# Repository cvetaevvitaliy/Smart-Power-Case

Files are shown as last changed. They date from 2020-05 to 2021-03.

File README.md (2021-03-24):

<div align="center">
 
 # Smart Power Case for FatShark, Skyzone, DJI fpv goggles
 
 
 
 
</div>

Smart Power Case for FatShark goggles <br>
Powered by a single Li-ion, stable output 8.2V or 12.6V (switching from menu)<br>
Support QC 2.0/3.0, FastCharge charges 5V, 9V, 12V - max input 18W (BQ25895) <br>
Shows operating time, remaining battery capacity, remaining charging time (BQ27441)<br>
<br>

## How to build 

###### Depends
You need install `gcc-arm-none-eabi` compiler and CMake  <br>
for Ubuntu <br>
 `sudo apt-get install gcc-arm-none-eabi cmake` <br>
for MacOS <br>
 `brew install gcc-arm-none-eabi cmake`
 
###### How to build project for STM32F103TBU
```
    git clone https://github.com/cvetaevvitaliy/Smart-Power-Case
    cd Smart-Power-Case
    mkdir build
    cd build
    cmake ..
    make -j8
```
default build for MCU STM32F103TBU (128kb flash ), if you need change type MCU - STM32F103T8U (64kb flash), please use option `-DTYPE_MCU=F103TBU` <br>
P.S. if you run `cmake ..` and want to use  `-DTYPE_MCU=F103T8U` You have two steps: <br>
First: you need delete build dir <br>
Second: remove `CMakeCache.txt` use `rm CMakeCache.txt` in build directory <br>

###### How to build project for STM32F103T8U
```$xslt
    git clone https://github.com/cvetaevvitaliy/Smart-Power-Case
    cd Smart-Power-Case
    mkdir build
    cd build
    cmake -DTYPE_MCU=F103T8U ..
    make -j8
```

Or use Clion IDE and load CMakeLists.txt file <br>

After a successful build, such files will be created<br>
:beer:   `firmware-x.x.x.bin` update for flash GUI flasher<br>
:beer:   `FullFW.bin` for flash via SWD flasher ST-link or Jlink<br>
:beers:   `FullFW.bin` has bootloader, firmware and default eeprom data<br>
<br>

#### Flash memory map for STM32F103TBU (128kb)
| 0x8000000 | 0x8000800 | 0x801FC00 | 
|:---:|:---:|:---:|
| bootloader | firmware | eeprom |
<br>

#### Flash memory map for STM32F103T8U (64kb)

| 0x8000000 | 0x8000800 | 0x800FC00 |
|:---:|:---:|:---:|
| bootloader | firmware | eeprom |

<br>
:white_check_mark: Since the data is not saved often, it made no sense to use an external eeprom

another options: `-DDEBUG=ON` for debug firmware via USB virtual comport, speed 115200, you can use `printf` and send out to console

*update project, added  support fw update from bootloader, use HID bootloader (https://github.com/cvetaevvitaliy/STM32_HID_Bootloader)<br>
*update project, added cross-platform command line flasher (https://github.com/cvetaevvitaliy/Flasher_USB_HID)<br> <br>
*update project, added cross-platform GUI flasher (https://github.com/cvetaevvitaliy/Smart-Power-Case-GUIFlasher)
Linux
MacOS
Win

YouTube link <br>https://www.youtube.com/watch?v=Y0oo7hjzqtc <br>
https://www.youtube.com/watch?v=4TmXY8NL-vo

<br><br> Download [Schematic.pdf](https://github.com/cvetaevvitaliy/Smart-Power-Case/blob/master/HW/schematic.pdf)
<br>
Download [Gerber X2.zip](https://github.com/cvetaevvitaliy/Smart-Power-Case/blob/master/HW/GerberX2_V2_2.zip)

Download STL for 3D printing <br>
MID https://github.com/cvetaevvitaliy/Smart-Power-Case/blob/master/HW/STL_File/mid.STL<br>
TOP https://github.com/cvetaevvitaliy/Smart-Power-Case/blob/master/HW/STL_File/top.STL<br>

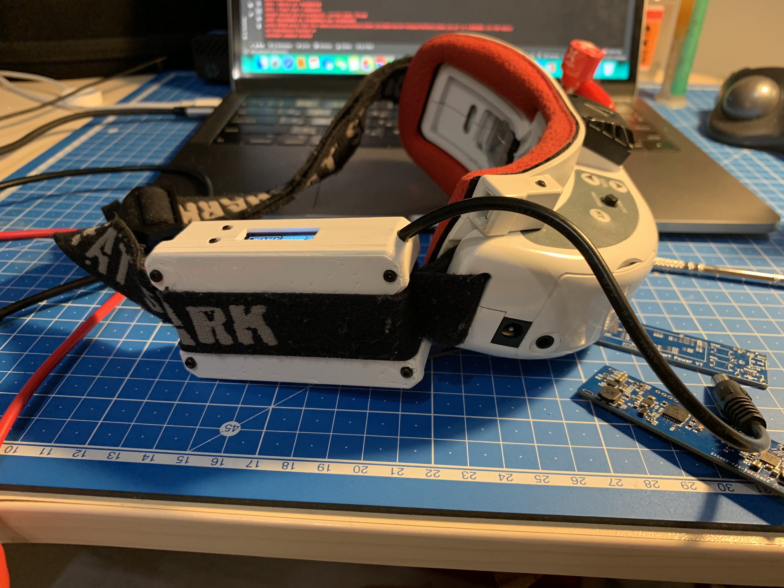
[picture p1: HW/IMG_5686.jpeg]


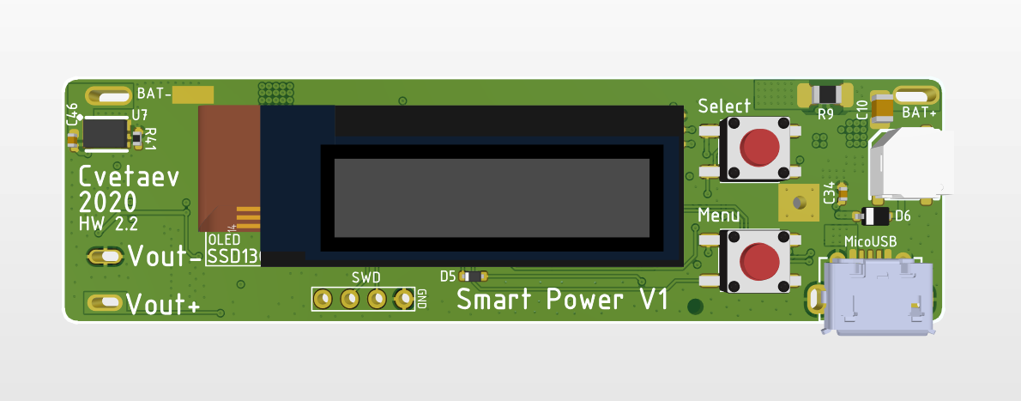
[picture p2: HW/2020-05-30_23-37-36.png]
TOP


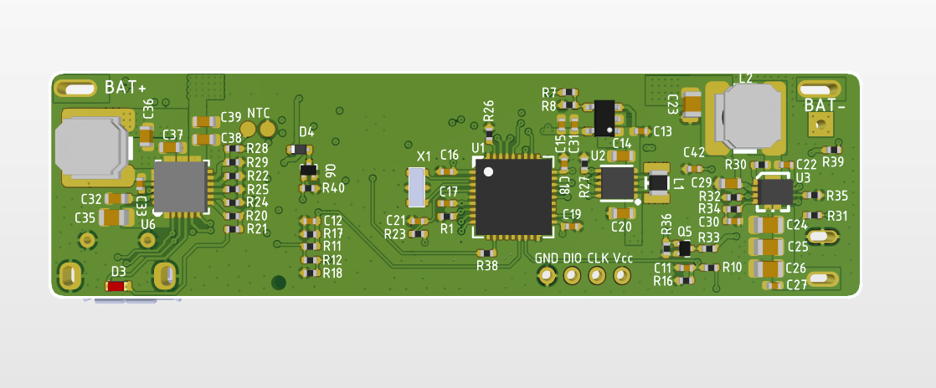
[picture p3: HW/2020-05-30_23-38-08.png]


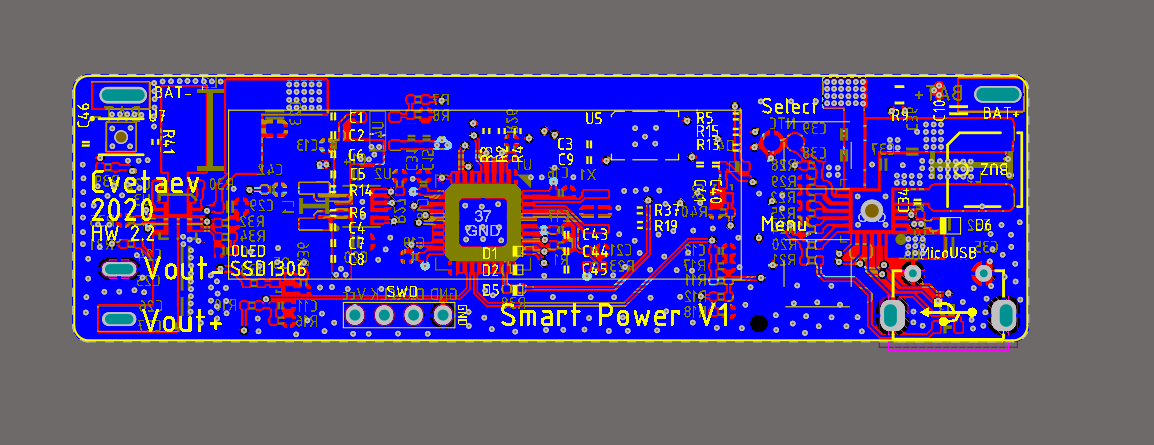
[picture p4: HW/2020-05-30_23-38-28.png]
Altium


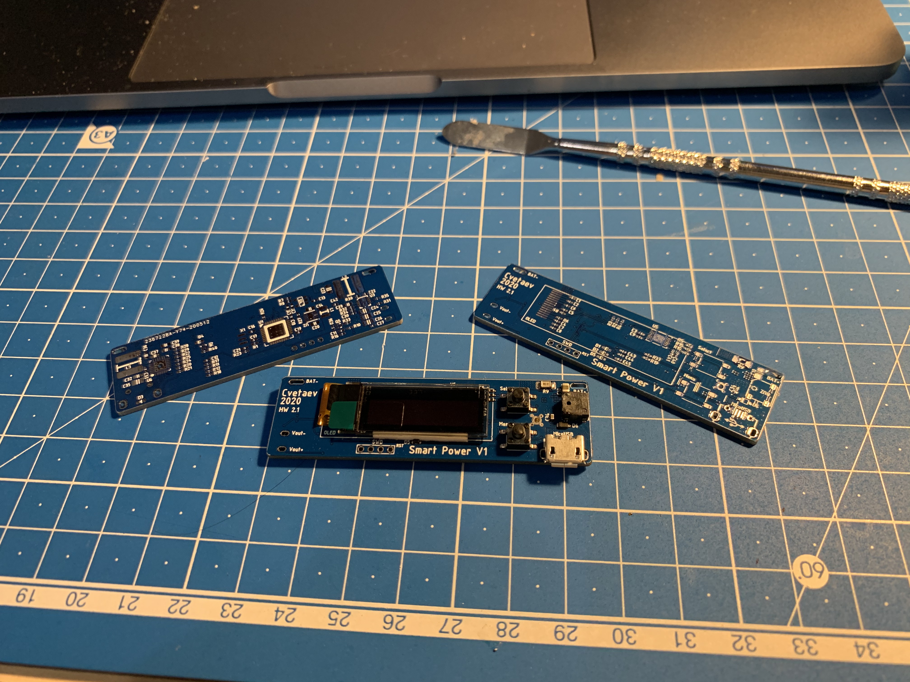
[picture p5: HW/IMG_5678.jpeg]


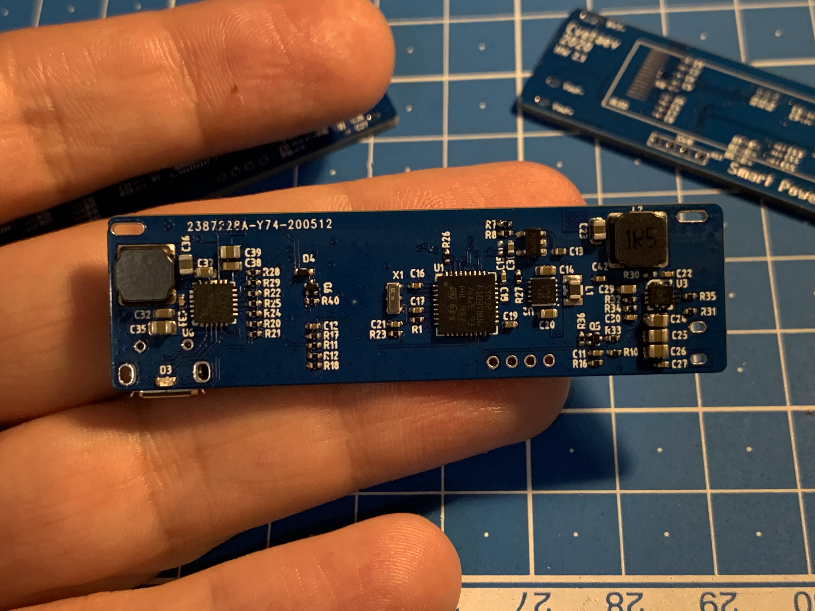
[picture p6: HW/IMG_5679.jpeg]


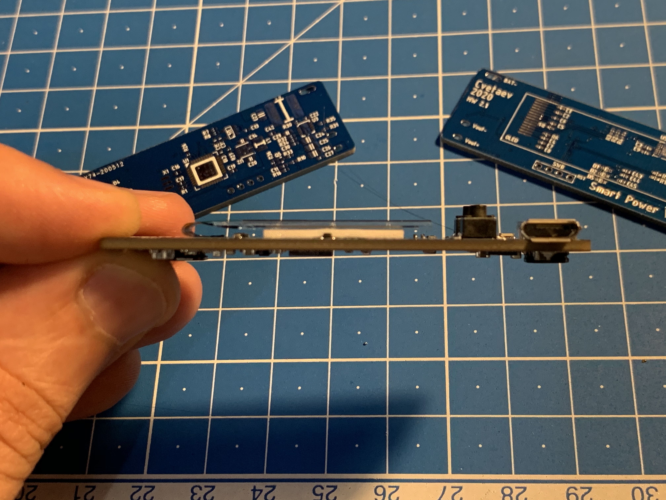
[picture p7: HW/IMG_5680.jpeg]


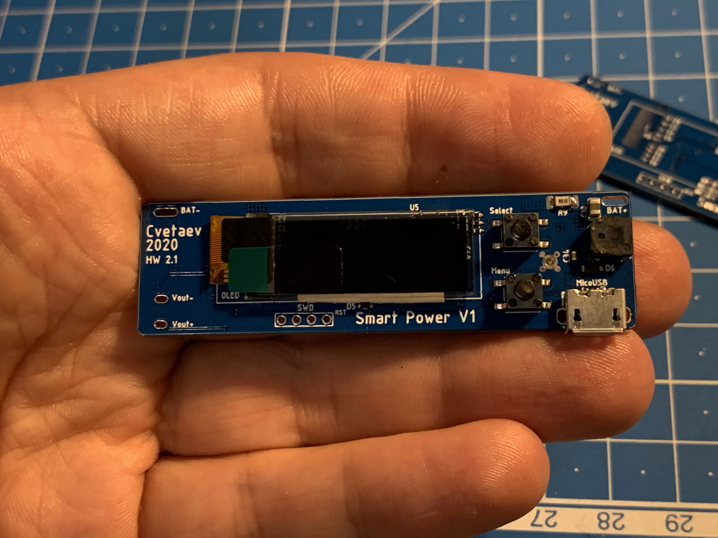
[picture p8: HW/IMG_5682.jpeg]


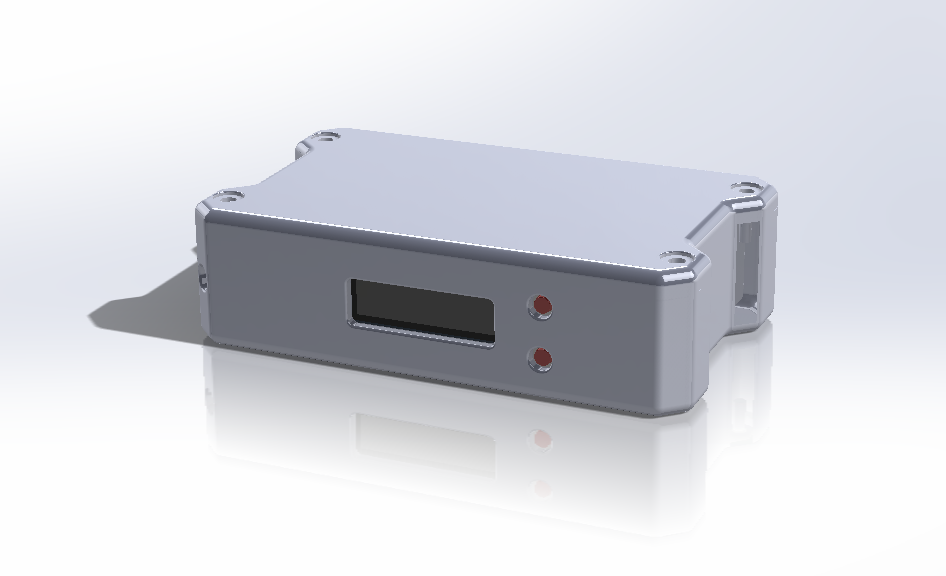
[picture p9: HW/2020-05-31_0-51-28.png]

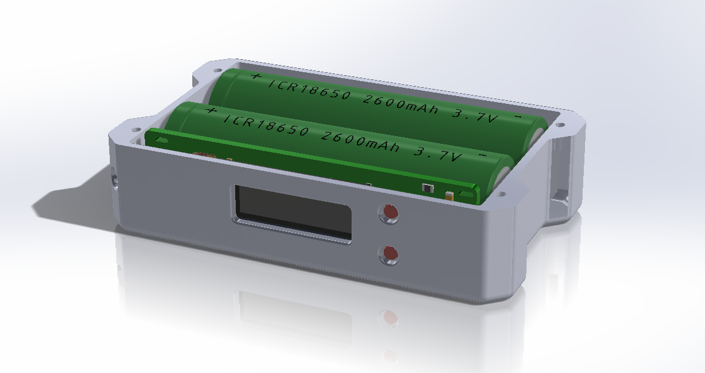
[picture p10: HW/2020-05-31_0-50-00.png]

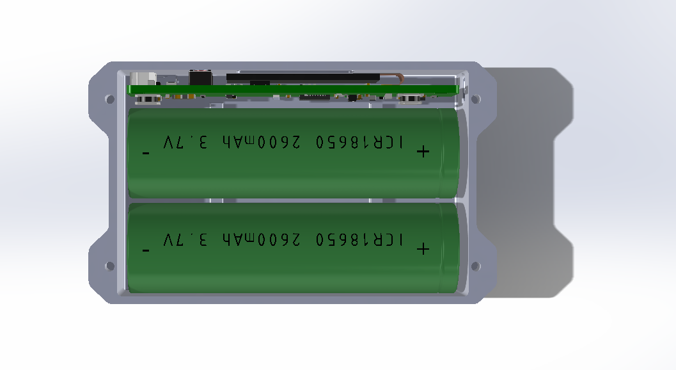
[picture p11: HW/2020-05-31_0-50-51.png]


See 3D model in the browser <br>
MID https://github.com/cvetaevvitaliy/Smart-Power-Case/blob/master/HW/STL_File/mid.STL<br>
TOP https://github.com/cvetaevvitaliy/Smart-Power-Case/blob/master/HW/STL_File/top.STL<br>

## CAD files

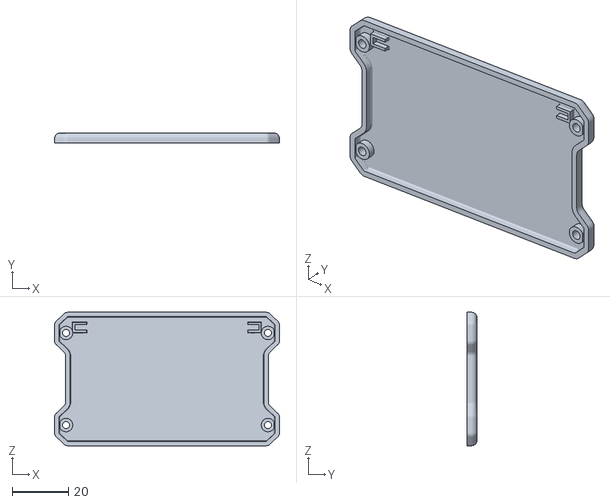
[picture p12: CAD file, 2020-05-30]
HW/STL_File/top.STL
80.0 x 3.60 x 47.5

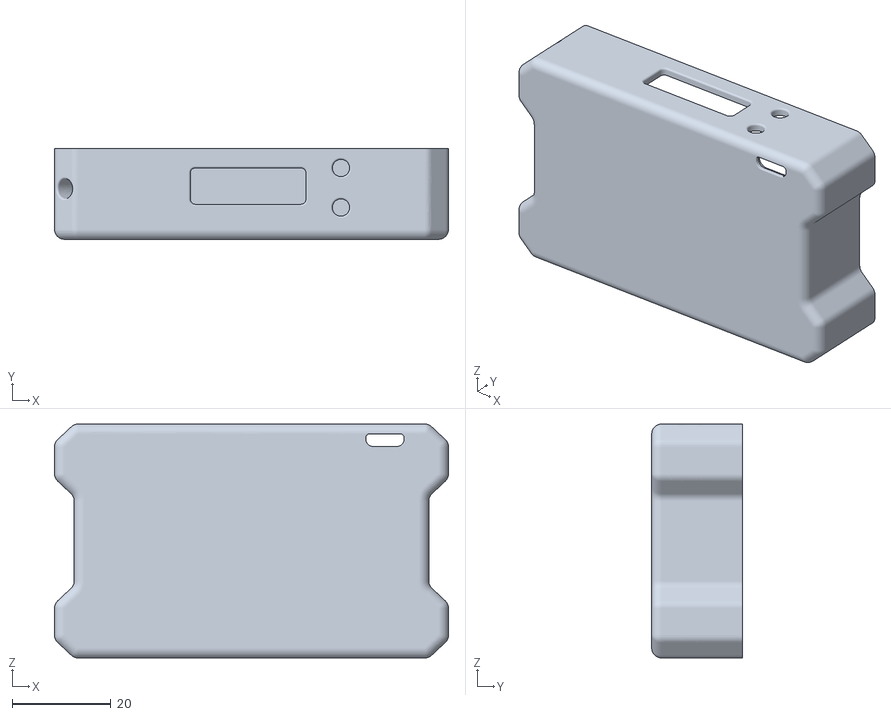
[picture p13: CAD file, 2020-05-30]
HW/STL_File/mid.STL
80.0 x 18.4 x 47.5

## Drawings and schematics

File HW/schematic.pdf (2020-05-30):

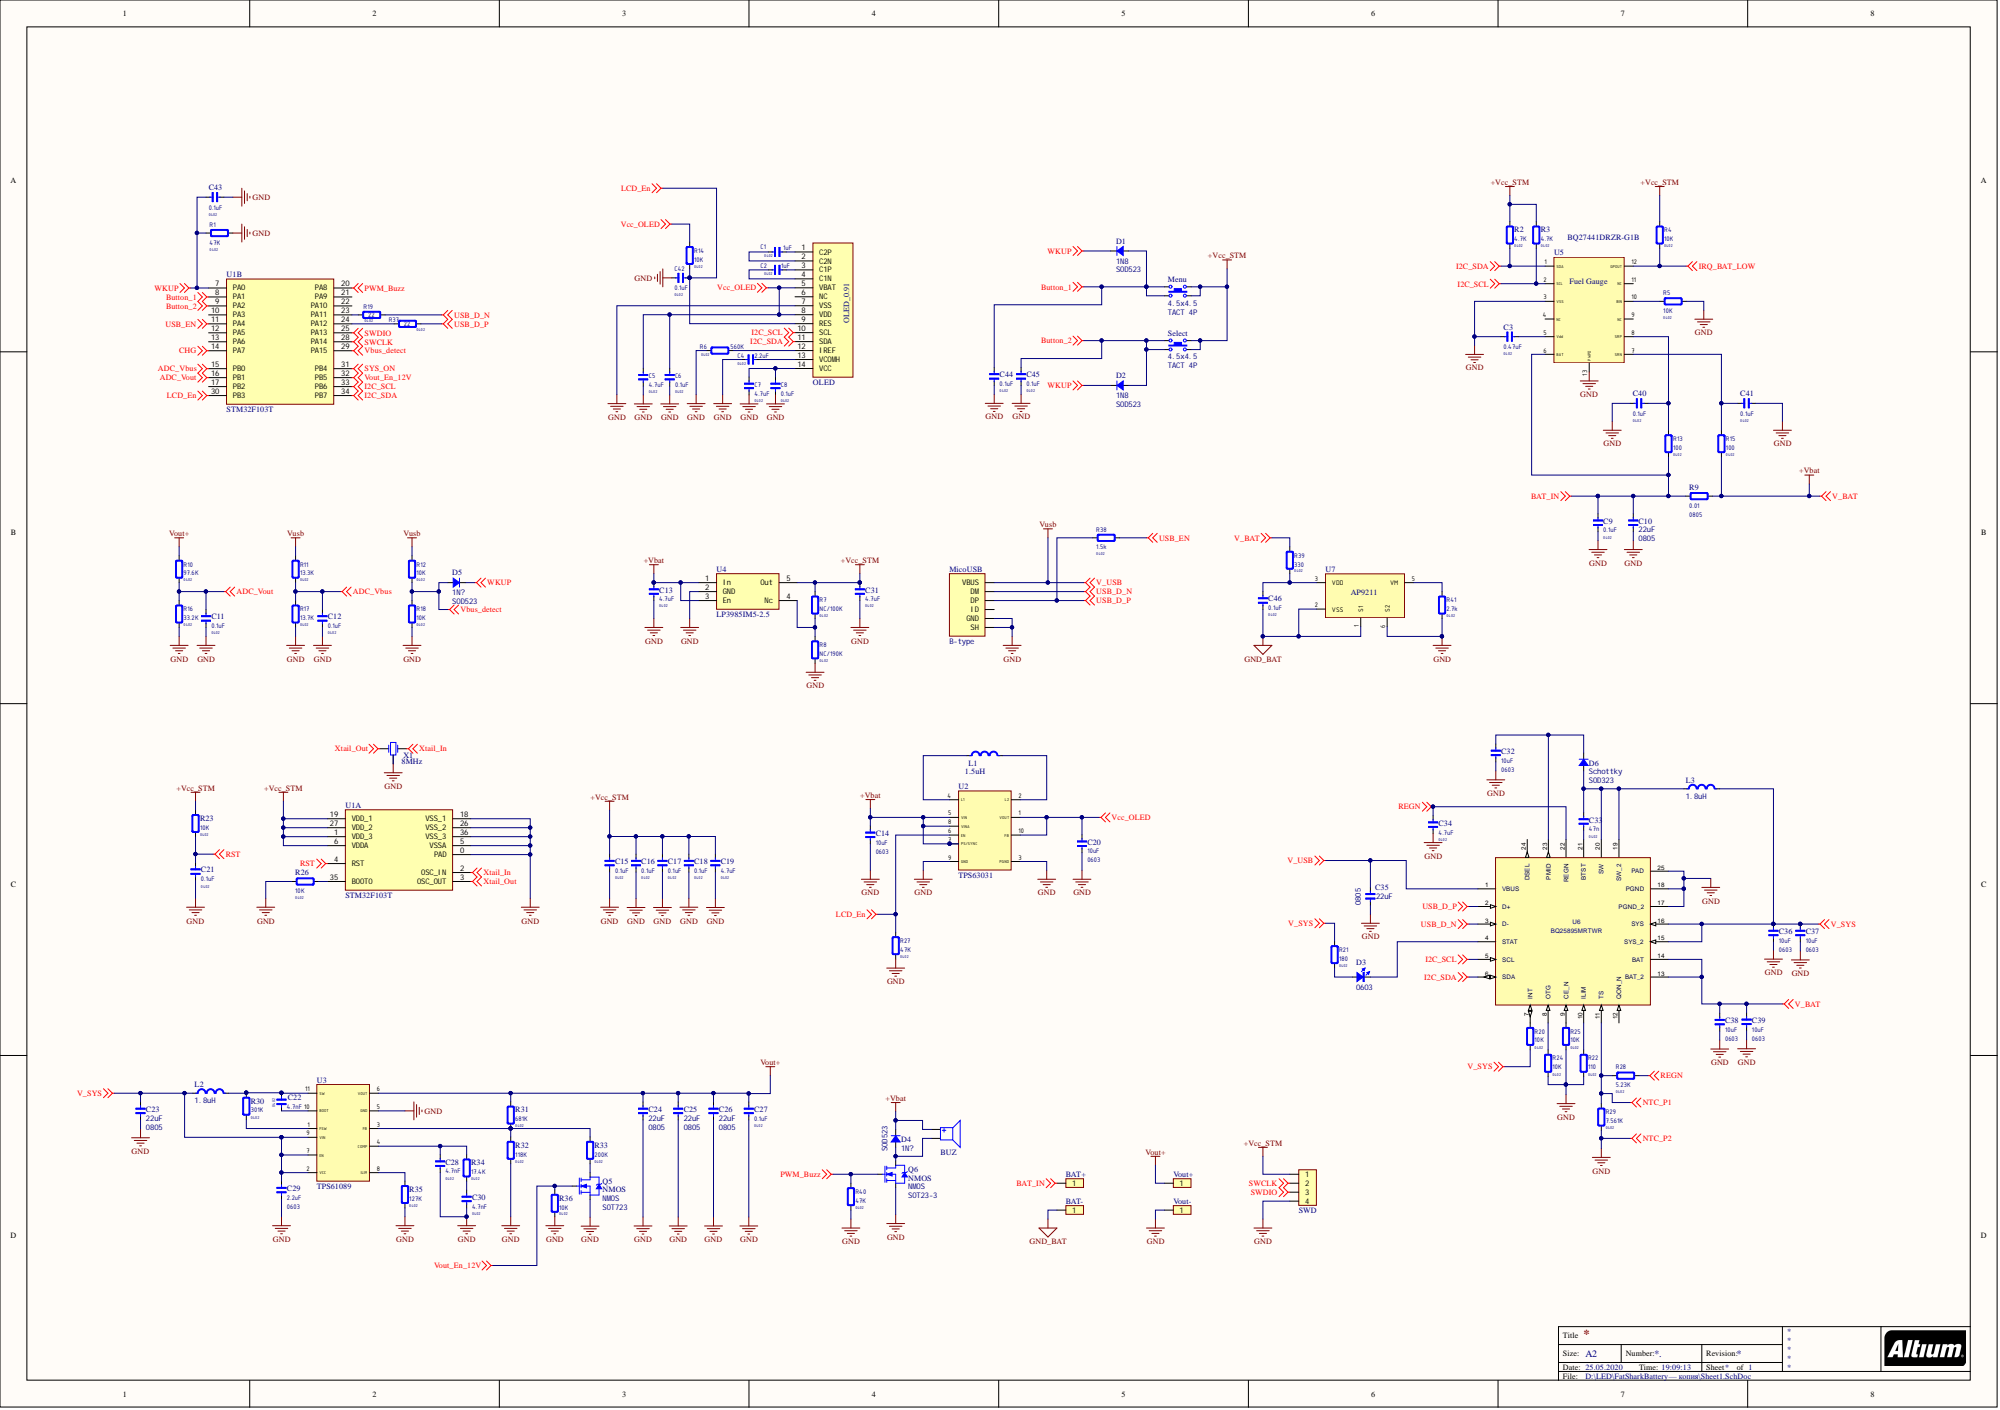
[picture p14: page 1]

PS/SYNC 7

Title * | * * * * *

Size: A2 | Number: *. | Revision: *
Date: 25.05.2020 Time: 19:09:13 | | Sheet * of 1

D:\LED\FatSharkBattery— копия\Sheet1.SchDoc

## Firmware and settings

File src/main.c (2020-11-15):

#include "main.h"
#include "stm32f1xx_hal.h"
#include "main_app.h"

ADC_HandleTypeDef hadc1;
DMA_HandleTypeDef hdma_adc1;

I2C_HandleTypeDef hi2c1;
DMA_HandleTypeDef hdma_i2c1_tx;
DMA_HandleTypeDef hdma_i2c1_rx;

RTC_HandleTypeDef hrtc;

TIM_HandleTypeDef htim1;
TIM_HandleTypeDef htim2;
TIM_HandleTypeDef htim3;

void SystemClock_Config(void);
static void MX_GPIO_Init(void);
static void MX_DMA_Init(void);
static void MX_I2C1_Init(void);
static void MX_ADC1_Init(void);
static void MX_TIM1_Init(void);
static void MX_TIM2_Init(void);
static void MX_TIM3_Init(void);
static void MX_RTC_Init(void);
static void USB_Reset_GPIO(void);
static inline void System_Init(void);

void HAL_TIM_MspPostInit(TIM_HandleTypeDef *htim);


int main(void) {

    System_Init();

    while (1) {
        App_Loop(); // main loop, what's "spinning" in the main_app module
    }

}

inline void System_Init(void){

    HAL_Init();
    SystemClock_Config();
    MX_GPIO_Init();
    MX_DMA_Init();
    MX_I2C1_Init();
    MX_ADC1_Init();
    MX_TIM1_Init();
    MX_TIM2_Init();
    MX_TIM3_Init();
    MX_RTC_Init();
    App_Setup();
    App_Init();
    if (!App_Check_StartUp())
        _Error_Handler(__FILE__, __LINE__);

}

void SystemClock_Config(void) {

    RCC_OscInitTypeDef RCC_OscInitStruct;
    RCC_ClkInitTypeDef RCC_ClkInitStruct;
    RCC_PeriphCLKInitTypeDef PeriphClkInit;

    /**Initializes the CPU, AHB and APB busses clocks 
    */
    RCC_OscInitStruct.OscillatorType = RCC_OSCILLATORTYPE_LSI | RCC_OSCILLATORTYPE_HSE;
    RCC_OscInitStruct.HSEState = RCC_HSE_ON;
    RCC_OscInitStruct.HSEPredivValue = RCC_HSE_PREDIV_DIV1;
    RCC_OscInitStruct.HSIState = RCC_HSI_ON;
    RCC_OscInitStruct.LSIState = RCC_LSI_ON;
    RCC_OscInitStruct.PLL.PLLState = RCC_PLL_ON;
    RCC_OscInitStruct.PLL.PLLSource = RCC_PLLSOURCE_HSE;
    RCC_OscInitStruct.PLL.PLLMUL = RCC_PLL_MUL6;
    if (HAL_RCC_OscConfig(&RCC_OscInitStruct) != HAL_OK) {
        _Error_Handler(__FILE__, __LINE__);
    }

    /**Initializes the CPU, AHB and APB busses clocks 
    */
    RCC_ClkInitStruct.ClockType = RCC_CLOCKTYPE_HCLK | RCC_CLOCKTYPE_SYSCLK
                                  | RCC_CLOCKTYPE_PCLK1 | RCC_CLOCKTYPE_PCLK2;
    RCC_ClkInitStruct.SYSCLKSource = RCC_SYSCLKSOURCE_PLLCLK;
    RCC_ClkInitStruct.AHBCLKDivider = RCC_SYSCLK_DIV1;
    RCC_ClkInitStruct.APB1CLKDivider = RCC_HCLK_DIV2;
    RCC_ClkInitStruct.APB2CLKDivider = RCC_HCLK_DIV2;

    if (HAL_RCC_ClockConfig(&RCC_ClkInitStruct, FLASH_LATENCY_1) != HAL_OK) {
        _Error_Handler(__FILE__, __LINE__);
    }

    PeriphClkInit.PeriphClockSelection = RCC_PERIPHCLK_RTC | RCC_PERIPHCLK_ADC
                                         | RCC_PERIPHCLK_USB;
    PeriphClkInit.RTCClockSelection = RCC_RTCCLKSOURCE_LSI;
    PeriphClkInit.AdcClockSelection = RCC_ADCPCLK2_DIV2;
    PeriphClkInit.UsbClockSelection = RCC_USBCLKSOURCE_PLL;
    if (HAL_RCCEx_PeriphCLKConfig(&PeriphClkInit) != HAL_OK) {
        _Error_Handler(__FILE__, __LINE__);
    }

    /**Configure the Systick interrupt time 
    */
    HAL_SYSTICK_Config(HAL_RCC_GetHCLKFreq() / 1000);

    /**Configure the Systick 
    */
    HAL_SYSTICK_CLKSourceConfig(SYSTICK_CLKSOURCE_HCLK);

    /* SysTick_IRQn interrupt configuration */
    HAL_NVIC_SetPriority(SysTick_IRQn, 0, 0);

    PWR->CSR |= PWR_CSR_EWUP; // Enable wakeup pin
    RCC->APB1ENR |= RCC_APB1ENR_PWREN; // enable clock for RTC BKP todo need debug
}

static void MX_ADC1_Init(void) {

    ADC_AnalogWDGConfTypeDef AnalogWDGConfig;
    ADC_ChannelConfTypeDef sConfig;

    /**Common config 
    */
    hadc1.Instance = ADC1;
    hadc1.Init.ScanConvMode = ADC_SCAN_ENABLE;
    hadc1.Init.ContinuousConvMode = ENABLE;
    hadc1.Init.DiscontinuousConvMode = DISABLE;
    hadc1.Init.ExternalTrigConv = ADC_SOFTWARE_START;
    hadc1.Init.DataAlign = ADC_DATAALIGN_RIGHT;
    hadc1.Init.NbrOfConversion = 3;
    if (HAL_ADC_Init(&hadc1) != HAL_OK) {
        _Error_Handler(__FILE__, __LINE__);
    }

    /**Configure Analog WatchDog 1 
    */
    AnalogWDGConfig.WatchdogMode = ADC_ANALOGWATCHDOG_SINGLE_REG;
    AnalogWDGConfig.HighThreshold = 0;
    AnalogWDGConfig.LowThreshold = 0;
    AnalogWDGConfig.Channel = ADC_CHANNEL_9;
    AnalogWDGConfig.ITMode = DISABLE;
    if (HAL_ADC_AnalogWDGConfig(&hadc1, &AnalogWDGConfig) != HAL_OK) {
        _Error_Handler(__FILE__, __LINE__);
    }

    /**Configure Regular Channel 
    */
    sConfig.Channel = ADC_CHANNEL_9;
    sConfig.Rank = ADC_REGULAR_RANK_1;
    sConfig.SamplingTime = ADC_SAMPLETIME_239CYCLES_5;
    if (HAL_ADC_ConfigChannel(&hadc1, &sConfig) != HAL_OK) {
        _Error_Handler(__FILE__, __LINE__);
    }

    /**Configure Regular Channel 
    */
    sConfig.Channel = ADC_CHANNEL_8;
    sConfig.Rank = ADC_REGULAR_RANK_2;
    if (HAL_ADC_ConfigChannel(&hadc1, &sConfig) != HAL_OK) {
        _Error_Handler(__FILE__, __LINE__);
    }

    /**Configure Regular Channel 
    */
    sConfig.Channel = ADC_CHANNEL_TEMPSENSOR;
    sConfig.Rank = ADC_REGULAR_RANK_3;
    if (HAL_ADC_ConfigChannel(&hadc1, &sConfig) != HAL_OK) {
        _Error_Handler(__FILE__, __LINE__);
    }

}

static void MX_I2C1_Init(void) {

    hi2c1.Instance = I2C1;
    hi2c1.Init.ClockSpeed = 100000;
    hi2c1.Init.DutyCycle = I2C_DUTYCYCLE_2;
    hi2c1.Init.OwnAddress1 = 0;
    hi2c1.Init.AddressingMode = I2C_ADDRESSINGMODE_7BIT;
    hi2c1.Init.DualAddressMode = I2C_DUALADDRESS_DISABLE;
    hi2c1.Init.OwnAddress2 = 0;
    hi2c1.Init.GeneralCallMode = I2C_GENERALCALL_DISABLE;
    hi2c1.Init.NoStretchMode = I2C_NOSTRETCH_DISABLE;
    if (HAL_I2C_Init(&hi2c1) != HAL_OK) {
        _Error_Handler(__FILE__, __LINE__);
    }

}

static void MX_RTC_Init(void) {

    /**Initialize RTC Only 
    */
    hrtc.Instance = RTC;
    hrtc.Init.AsynchPrediv = RTC_AUTO_1_SECOND;
    hrtc.Init.OutPut = RTC_OUTPUTSOURCE_ALARM;
    if (HAL_RTC_Init(&hrtc) != HAL_OK) {
        _Error_Handler(__FILE__, __LINE__);
    }

}

static void MX_TIM1_Init(void) {

    TIM_ClockConfigTypeDef sClockSourceConfig;
    TIM_MasterConfigTypeDef sMasterConfig;
    TIM_OC_InitTypeDef sConfigOC;
    TIM_BreakDeadTimeConfigTypeDef sBreakDeadTimeConfig;

    htim1.Instance = TIM1;
    htim1.Init.Prescaler = 210;
    htim1.Init.CounterMode = TIM_COUNTERMODE_UP;
    htim1.Init.Period = 140;
    htim1.Init.ClockDivision = TIM_CLOCKDIVISION_DIV1;
    htim1.Init.RepetitionCounter = 0;
    htim1.Init.AutoReloadPreload = TIM_AUTORELOAD_PRELOAD_DISABLE;
    if (HAL_TIM_Base_Init(&htim1) != HAL_OK) {
        _Error_Handler(__FILE__, __LINE__);
    }

    sClockSourceConfig.ClockSource = TIM_CLOCKSOURCE_INTERNAL;
    if (HAL_TIM_ConfigClockSource(&htim1, &sClockSourceConfig) != HAL_OK) {
        _Error_Handler(__FILE__, __LINE__);
    }

    if (HAL_TIM_PWM_Init(&htim1) != HAL_OK) {
        _Error_Handler(__FILE__, __LINE__);
    }

    sMasterConfig.MasterOutputTrigger = TIM_TRGO_RESET;
    sMasterConfig.MasterSlaveMode = TIM_MASTERSLAVEMODE_DISABLE;
    if (HAL_TIMEx_MasterConfigSynchronization(&htim1, &sMasterConfig) != HAL_OK) {
        _Error_Handler(__FILE__, __LINE__);
    }

    sConfigOC.OCMode = TIM_OCMODE_PWM1;
    sConfigOC.Pulse = 70;
    sConfigOC.OCPolarity = TIM_OCPOLARITY_HIGH;
    sConfigOC.OCNPolarity = TIM_OCNPOLARITY_HIGH;
    sConfigOC.OCFastMode = TIM_OCFAST_DISABLE;
    sConfigOC.OCIdleState = TIM_OCIDLESTATE_RESET;
    sConfigOC.OCNIdleState = TIM_OCNIDLESTATE_RESET;
    if (HAL_TIM_PWM_ConfigChannel(&htim1, &sConfigOC, TIM_CHANNEL_1) != HAL_OK) {
        _Error_Handler(__FILE__, __LINE__);
    }

    sBreakDeadTimeConfig.OffStateRunMode = TIM_OSSR_DISABLE;
    sBreakDeadTimeConfig.OffStateIDLEMode = TIM_OSSI_DISABLE;
    sBreakDeadTimeConfig.LockLevel = TIM_LOCKLEVEL_OFF;
    sBreakDeadTimeConfig.DeadTime = 0;
    sBreakDeadTimeConfig.BreakState = TIM_BREAK_DISABLE;
    sBreakDeadTimeConfig.BreakPolarity = TIM_BREAKPOLARITY_HIGH;
    sBreakDeadTimeConfig.AutomaticOutput = TIM_AUTOMATICOUTPUT_DISABLE;
    if (HAL_TIMEx_ConfigBreakDeadTime(&htim1, &sBreakDeadTimeConfig) != HAL_OK) {
        _Error_Handler(__FILE__, __LINE__);
    }

    HAL_TIM_MspPostInit(&htim1);

}

static void MX_TIM2_Init(void) {

    TIM_ClockConfigTypeDef sClockSourceConfig;
    TIM_MasterConfigTypeDef sMasterConfig;

    htim2.Instance = TIM2;
    htim2.Init.Prescaler = 580;
    htim2.Init.CounterMode = TIM_COUNTERMODE_UP;
    htim2.Init.Period = 2000;
    htim2.Init.ClockDivision = TIM_CLOCKDIVISION_DIV1;
    htim2.Init.AutoReloadPreload = TIM_AUTORELOAD_PRELOAD_DISABLE;
    if (HAL_TIM_Base_Init(&htim2) != HAL_OK) {
        _Error_Handler(__FILE__, __LINE__);
    }

    sClockSourceConfig.ClockSource = TIM_CLOCKSOURCE_INTERNAL;
    if (HAL_TIM_ConfigClockSource(&htim2, &sClockSourceConfig) != HAL_OK) {
        _Error_Handler(__FILE__, __LINE__);
    }

    sMasterConfig.MasterOutputTrigger = TIM_TRGO_RESET;
    sMasterConfig.MasterSlaveMode = TIM_MASTERSLAVEMODE_DISABLE;
    if (HAL_TIMEx_MasterConfigSynchronization(&htim2, &sMasterConfig) != HAL_OK) {
        _Error_Handler(__FILE__, __LINE__);
    }

}

/* TIM3 init function */
static void MX_TIM3_Init(void)
{

    TIM_ClockConfigTypeDef sClockSourceConfig;
    TIM_MasterConfigTypeDef sMasterConfig;

    htim3.Instance = TIM3;
    htim3.Init.Prescaler = 48000;
    htim3.Init.CounterMode = TIM_COUNTERMODE_UP;
    htim3.Init.Period = 25;
    htim3.Init.ClockDivision = TIM_CLOCKDIVISION_DIV1;
    htim3.Init.AutoReloadPreload = TIM_AUTORELOAD_PRELOAD_DISABLE;
    if (HAL_TIM_Base_Init(&htim3) != HAL_OK)
    {
        _Error_Handler(__FILE__, __LINE__);
    }

    sClockSourceConfig.ClockSource = TIM_CLOCKSOURCE_INTERNAL;
    if (HAL_TIM_ConfigClockSource(&htim3, &sClockSourceConfig) != HAL_OK)
    {
        _Error_Handler(__FILE__, __LINE__);
    }

    sMasterConfig.MasterOutputTrigger = TIM_TRGO_RESET;
    sMasterConfig.MasterSlaveMode = TIM_MASTERSLAVEMODE_DISABLE;
    if (HAL_TIMEx_MasterConfigSynchronization(&htim3, &sMasterConfig) != HAL_OK)
    {
        _Error_Handler(__FILE__, __LINE__);
    }

}

/** 
  * Enable DMA controller clock
  */
static void MX_DMA_Init(void) {
    /* DMA controller clock enable */
    __HAL_RCC_DMA1_CLK_ENABLE();

    /* DMA interrupt init */
    /* DMA1_Channel1_IRQn interrupt configuration */
    HAL_NVIC_SetPriority(DMA1_Channel1_IRQn, 0, 0);
    HAL_NVIC_EnableIRQ(DMA1_Channel1_IRQn);
    /* DMA1_Channel6_IRQn interrupt configuration */
    HAL_NVIC_SetPriority(DMA1_Channel6_IRQn, 0, 0);
    HAL_NVIC_EnableIRQ(DMA1_Channel6_IRQn);
    /* DMA1_Channel7_IRQn interrupt configuration */
    HAL_NVIC_SetPriority(DMA1_Channel7_IRQn, 0, 0);
    HAL_NVIC_EnableIRQ(DMA1_Channel7_IRQn);
}

/** Configure pins as 
        * Analog 
        * Input 
        * Output
        * EVENT_OUT
        * EXTI
*/
static void MX_GPIO_Init(void) {

    GPIO_InitTypeDef GPIO_InitStruct;

    /* GPIO Ports Clock Enable */
    __HAL_RCC_GPIOD_CLK_ENABLE();
    __HAL_RCC_GPIOA_CLK_ENABLE();
    __HAL_RCC_GPIOB_CLK_ENABLE();

    /*Configure GPIO pin Output Level */
    HAL_GPIO_WritePin(GPIOA, USB_En_Pin | Bust_En_Pin, GPIO_PIN_RESET);

    /*Configure GPIO pin Output Level */
    HAL_GPIO_WritePin(GPIOB, LCD_En_Pin | SYS_On_Pin | Vout_En_12V_Pin, GPIO_PIN_RESET);

    /*Configure GPIO pins : Button_Menu_Pin Button_Select_Pin CHG_Pin Vbus_detect_Pin */
    GPIO_InitStruct.Pin = Button_Menu_Pin | Button_Select_Pin | CHG_Pin | Vbus_detect_Pin;
    GPIO_InitStruct.Mode = GPIO_MODE_IT_RISING;
    GPIO_InitStruct.Pull = GPIO_PULLDOWN;
    HAL_GPIO_Init(GPIOA, &GPIO_InitStruct);

    /*Configure GPIO pins : USB_En_Pin Bust_En_Pin */
    GPIO_InitStruct.Pin = USB_En_Pin | Bust_En_Pin;
    GPIO_InitStruct.Mode = GPIO_MODE_OUTPUT_PP;
    GPIO_InitStruct.Pull = GPIO_NOPULL;
    GPIO_InitStruct.Speed = GPIO_SPEED_FREQ_LOW;
    HAL_GPIO_Init(GPIOA, &GPIO_InitStruct);

    /*Configure GPIO pins : LCD_En_Pin SYS_On_Pin Vout_En_12V_Pin */
    GPIO_InitStruct.Pin = LCD_En_Pin | SYS_On_Pin | Vout_En_12V_Pin;
    GPIO_InitStruct.Mode = GPIO_MODE_OUTPUT_PP;
    GPIO_InitStruct.Pull = GPIO_NOPULL;
    GPIO_InitStruct.Speed = GPIO_SPEED_FREQ_LOW;
    HAL_GPIO_Init(GPIOB, &GPIO_InitStruct);

    /* EXTI interrupt init*/
    HAL_NVIC_SetPriority(EXTI1_IRQn, 0, 0);
    HAL_NVIC_EnableIRQ(EXTI1_IRQn);

    HAL_NVIC_SetPriority(EXTI2_IRQn, 0, 0);
    HAL_NVIC_EnableIRQ(EXTI2_IRQn);

    HAL_NVIC_SetPriority(EXTI9_5_IRQn, 0, 0);
    HAL_NVIC_EnableIRQ(EXTI9_5_IRQn);

    HAL_NVIC_SetPriority(EXTI15_10_IRQn, 0, 0);
    HAL_NVIC_EnableIRQ(EXTI15_10_IRQn);

}

void USB_Reset_GPIO(void) {
    GPIO_InitTypeDef GPIO_InitStruct;

    GPIO_InitStruct.Pin = GPIO_PIN_12;
    GPIO_InitStruct.Mode = GPIO_MODE_OUTPUT_PP;
    GPIO_InitStruct.Pull = GPIO_NOPULL;
    GPIO_InitStruct.Speed = GPIO_SPEED_FREQ_LOW;
    HAL_GPIO_Init(GPIOA, &GPIO_InitStruct);

    HAL_GPIO_WritePin(GPIOA, GPIO_PIN_12, GPIO_PIN_RESET);

    HAL_Delay(100);
    HAL_GPIO_DeInit(GPIOA, GPIO_PIN_12);

}

/**
  * @brief  This function is executed in case of error occurrence.
  * @param  file: The file name as string.
  * @param  line: The line in file as a number.
  * @retval None
  */
void _Error_Handler(char *file, int line) {
    /* User can add his own implementation to report the HAL error return state */
    HAL_RTCEx_BKUPWrite(&hrtc, 4, 0x424C);
    HAL_Delay(1000);
    while (1) {
        NVIC_SystemReset();
    }
}

#ifdef  USE_FULL_ASSERT
/**
  * @brief  Reports the name of the source file and the source line number
  *         where the assert_param error has occurred.
  * @param  file: pointer to the source file name
  * @param  line: assert_param error line source number
  * @retval None
  */
void assert_failed(uint8_t* file, uint32_t line)
{
  /* User can add his own implementation to report the file name and line number,
     tex: printf("Wrong parameters value: file %s on line %d\r\n", file, line) */
}
#endif /* USE_FULL_ASSERT */

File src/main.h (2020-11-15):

#ifndef __MAIN_H__
#define __MAIN_H__
#include "tinyprintf.h"
#define Error_Handler() _Error_Handler(__FILE__, __LINE__)

#define Button_Menu_Pin GPIO_PIN_1
#define ButtonMenu_GPIO_Port GPIOA
#define ButtonMenu_EXTI_IRQn EXTI1_IRQn
#define Button_Select_Pin GPIO_PIN_2
#define ButtonSelect_GPIO_Port GPIOA
#define ButtonSelect_EXTI_IRQn EXTI2_IRQn
#define USB_En_Pin GPIO_PIN_4
#define USB_En_GPIO_Port GPIOA
#define Bust_En_Pin GPIO_PIN_5
#define Bust_En_GPIO_Port GPIOA
#define CHG_Pin GPIO_PIN_7
#define CHG_GPIO_Port GPIOA
#define CHG_EXTI_IRQn EXTI9_5_IRQn
#define PWM_Buzz_Pin GPIO_PIN_8
#define PWM_Buzz_GPIO_Port GPIOA
#define Vbus_detect_Pin GPIO_PIN_15
#define Vbus_detect_GPIO_Port GPIOA
#define Vbus_detect_EXTI_IRQn EXTI15_10_IRQn
#define LCD_En_Pin GPIO_PIN_3
#define LCD_En_GPIO_Port GPIOB
#define SYS_On_Pin GPIO_PIN_4
#define SYS_On_GPIO_Port GPIOB
#define Vout_En_12V_Pin GPIO_PIN_5
#define Vout_En_12V_GPIO_Port GPIOB


void _Error_Handler(char *, int);

#endif

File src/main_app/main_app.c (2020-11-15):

/********************************
* Created by Vitaliy on 4/28/20.
********************************/
#include "main_app.h"
#include "adc.h"
#include "OLED_UI.h"
#include "button.h"
#include "Power.h"
#include "Settings_Eeprom.h"
#include "Debug.h"
#include "cli.h"

#define MAGIC_BKP_VALUE_BOOT                   ((uint32_t)0x424C) /// this value for write to BKP RTC register, to enable bootloader after reboot
#define MAGIC_BKP_VALUE_BQ                     ((uint32_t)0x425C)

extern DMA_HandleTypeDef hdma_adc1;
extern I2C_HandleTypeDef hi2c1;
extern RTC_HandleTypeDef hrtc;
extern TIM_HandleTypeDef htim2;

static Device_Status_t Device_Status = {0};

static void Time_Task(Device_Status_t *Data);
static void Enter_DFU_Mode(Device_Status_t *Data);

void App_Setup(void){

    HAL_TIM_Base_Start_IT(&htim2);
    //Settings_SetDefault(&Device_Status.Device_Settings);
    Settings_Get(&Device_Status.Device_Settings);
    if (Device_Status.Device_Settings.low_volt < 250 || Device_Status.Device_Settings.low_volt > 400) {
        Settings_SetDefault(&Device_Status.Device_Settings);
    }
}

void App_Init(void){

    CLI_Init(CLI_TDC_None);
    CLI_cmd_init();

    if (Power_ChargerInit() == false){
        Device_Status.Device_Error = Device_Error_BQ25895;
        Device_Status.system_critical_error = true;
#if 0
        LOG_DEBUG("ADC BQ25895\n");
#endif
    }

    if (ADC_Init() == false){
        Device_Status.Device_Error = Device_Error_ADC;
        Device_Status.system_critical_error = true;
#if 0
        LOG_DEBUG("ADC Error\n");
#endif
    }
    if (BQ27441_init() == false) {
        Device_Status.Device_Error = Device_Error_BQ27441;
        Device_Status.system_critical_error = true;
#if 0
        LOG_DEBUG("BQ27441 not found\n");
#endif
    }

    Power_OLEDOn(true);
    Power_BoostEnable(true);
    if (ssd1306_Init() == false) {
        Device_Status.Device_Error = Device_Error_SSD1306;
        Device_Status.system_critical_error = true;
#if 0
        LOG_DEBUG("ssd1306 not found\n");
#endif
        Power_OLEDOn(false);
        Power_SystemOn(false);
        Power_BoostEnable(false);
    } else {
        ssd1306_Draw_String("System Init", 20, 10, &Font_8x10);
        ssd1306_Draw_String(SOFTWARE_VERSION, 40, 20,&Font_8x10);
        ssd1306_UpdateScreen();
        HAL_Delay(1500);
        ssd1306_Clear();
    }

}

bool App_Check_StartUp(void){

    if (Device_Status.system_critical_error == true){
#if 0
        LOG_DEBUG("Error %d\n", Device_Status.Device_Error);
#endif
        if (Device_Status.Device_Error != Device_Error_SSD1306) {
            ssd1306_Draw_String("Error System", 0, 0, &Font_8x10);
            ssd1306_Draw_String(print_error[Device_Status.Device_Error], 0, 10, &Font_8x10);
            ssd1306_UpdateScreen();
            HAL_Delay(2000);
            ssd1306_Clear();
        }
        return false;
    } else {
        Power_SystemOn(true);
        Power_BoostEnable(true);
        if (Device_Status.Device_Settings.Boost_mode == Boost_12V)
            Power_BoostEnable12V(true);
        else
            Power_BoostEnable12V(false);
    }

    if (HAL_RTCEx_BKUPRead(&hrtc, 8) != MAGIC_BKP_VALUE_BQ){
        HAL_RTCEx_BKUPWrite(&hrtc, 8, MAGIC_BKP_VALUE_BQ);
        ssd1306_Draw_String("Reset BQ27441", 0, 0, &Font_8x10);
        ssd1306_UpdateScreen();
        BQ27441_Full_Reset();
        HAL_Delay(5000);
    }


    if (BQ27441_itporFlag() ) {
        ssd1306_Draw_String("Find NEW BAT", 0, 0, &Font_8x10);
        ssd1306_Draw_String("Please", 0, 10, &Font_8x10);
        ssd1306_Draw_String("Recalibrate", 0, 20, &Font_8x10);
        ssd1306_UpdateScreen();
        Device_Status.need_calibrate = true;
        HAL_Delay(2000);
    } else {
        Device_Status.need_calibrate = false;
        //BQ27441_CLEAR_HIBERNATE();
        //Settings_SetMinLiionVoltPowerOff((Device_Status.Device_Settings.low_volt * 10));
    }
    return true;

}


void App_Loop(void){

    Time_Task(&Device_Status);
    //ADC_Task(&Device_Status.ADC_Data);
    Button_Task(&Device_Status.Device_Settings);
    OLED_UI_Task(&Device_Status);
    Power_BatteryTask(&Device_Status);
    Power_ChargerTask(&Device_Status.ChargeChip);
#if 0
    Debug_Task(&Device_Status);
#endif

    Enter_DFU_Mode(&Device_Status);
    if (Get_Enable_USB())
        CLI_Service();


    if (!Device_Status.Device_Settings.locked_power_off && Device_Status.ChargeChip.charging_status == 0){
        if (Button_GetState(Button_select)){
            Power_DCDC();
            Device_Status.time_for_auto_off = 0;
        }

    }

}

static void Time_Task(Device_Status_t *Data){

    static uint32_t last_time = 0;
    if (HAL_GetTick() - last_time > 1000){
        last_time = HAL_GetTick();
        Data->work_time_second++;
        if (Data->work_time_second == 60){
            Data->work_time_minute++;
            if (Data->ChargeChip.Vbus < 3500)
                Data->time_for_auto_off++;
            Data->work_time_second = 0;
            if (Data->work_time_minute == 60) {
                Data->work_time_minute = 0;
                Data->work_time_hours++;
                if (Data->work_time_hours == 10) {
                    Data->work_time_hours = 0;
                }
            }
        }
    }
    Power_DevicePowerOffTimer(Data);
}

static void Enter_DFU_Mode(Device_Status_t *Data) {

    if (HAL_GPIO_ReadPin(ButtonMenu_GPIO_Port, Button_Menu_Pin) &&
        HAL_GPIO_ReadPin(ButtonSelect_GPIO_Port, Button_Select_Pin)) {
        if (Data->ChargeChip.vbus_type == BQ2589X_VBUS_USB_SDP || Data->ChargeChip.vbus_type == BQ2589X_VBUS_USB_CDP) {
            Data->ADC_Data.Vbus = 0;
            Activate_DFU();
        } else {
            ssd1306_Clear();
            ssd1306_Draw_String("Reboot", 30, 10, &Font_8x10);
            ssd1306_UpdateScreen();
            HAL_Delay(1000);
            NVIC_SystemReset(); // Uncomment this, if need reset for debug FW
        }

    }
}


Device_Status_t* Get_Device_Status(void){

    return &Device_Status;
}

void Activate_DFU(void){
    ssd1306_Clear();
    ssd1306_Draw_String("DFU 3.0", 30, 10, &Font_8x10);
    ssd1306_UpdateScreen();
    HAL_RTCEx_BKUPWrite(&hrtc, 4, MAGIC_BKP_VALUE_BOOT);
    HAL_Delay(1000);
    NVIC_SystemReset();

}

bool Settings_Get_Buzzer(void){

    Settings_Get(&Device_Status.Device_Settings);
    return Device_Status.Device_Settings.buzzer_enable;
}

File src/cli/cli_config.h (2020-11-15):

/*************************************************************************
 *
 *			CLI configure file
 *
 *	---------------------------------------------------------------------
 *
 *
 ************************************************************************/

#ifndef _CLI_CONFIG_H_
#define _CLI_CONFIG_H_

#include <stdbool.h>
#include <stdint.h>
#include <stdlib.h>
#include <string.h>
#include "cli.h"
#include "tinyprintf.h"


// ****************************** Code keys ********************************

#define _KEY_INIT(c)                       ((char)c)

#define TERM_KEY_ENTER                      (_KEY_INIT(0x0D))        // Enter command symbol
#define TERM_KEY_BACKSPACE                  (_KEY_INIT(0x08))        // Delete character before cursor position
#define TERM_KEY_LSHIFT                     (_KEY_INIT(0x08))        // Left shift symbol
#define TERM_KEY_ESCAPE                     (_KEY_INIT(0xF0))        // Exception execute command symbol
#define TERM_KEY_UP                         (_KEY_INIT(0xF1))        // KeyUp symbol
#define TERM_KEY_RIGHT                      (_KEY_INIT(0xF2))        // KeyRight symbol
#define TERM_KEY_DOWN                       (_KEY_INIT(0xF3))        // KeyDown symbol
#define TERM_KEY_LEFT                       (_KEY_INIT(0xF4))        // KeyLeft symbol
#define TERM_KEY_DEL                        (_KEY_INIT(0xF5))        // Delete character after cursor position
#define TERM_KEY_HOME                       (_KEY_INIT(0xA0))        // Home key
#define TERM_KEY_END                        (_KEY_INIT(0xA1))        // End key
#define TERM_KEY_TAB                        (_KEY_INIT(0x09))        // TAB key
#define TERM_KEY_CONF                       (_KEY_INIT(0x60))        // Configurator

// **************************************************************************

// **********************    CLI Settings   *********************************

#ifndef GIT_BRANCH
#define GIT_BRANCH               ("__________")   //If no version has been specified -DGIT_BRANCH will be empty
#endif
#ifndef GIT_HASH
#define GIT_HASH                 ("________")     //If no version has been specified -GIT_HASH will be empty
#endif
#ifndef MINOR
#define MINOR                    ("_")            //If no version has been specified -GMINOR will be empty
#endif
#ifndef MAJOR
#define MAJOR                    ("_")            //If no version has been specified -GMAJOR will be empty
#endif
#ifndef PATCH
#define PATCH                    ("_")            //If no version has been specified -GPATCH will be empty
#endif
#ifndef MCU
#define MCU                    ("_________")      //If no version has been specified -GMCU will be empty
#endif

#define _TERM_VER_                      ("v0.0.2")          // Terminal version
#define CLI_SIZE_TASK                   (20)                // Max number of commands
#define CLI_CMD_BUF_SIZE                (40)                // Max number of character buffer string command
#define CLI_CMD_LOG_SIZE                (10)                // Max number of loging command
#define CLI_ARGS_BUF_SIZE               (10)                // Max number of arguments in one command
#define CLI_ARG_SIZE                    (5)                 // Max number character of one arguments
#define CHAR_INTERRUPT                  (0x03)              // Abort execute command key-code symbol
#define STRING_TERM_ENTER               ("\n\r")            // String new line
#define STRING_TERM_ARROW               (">> ")             // String arrow enter

#define CLI_TIMELEFT_EN                     (1)            // Calculate time (If you need performance, don't turn it on )
#define CLI_CMD_LOG_EN                      (1)            // Command logging (history)
#define CLI_CMD_AUTOCMPLT_EN                (1)            // Command AutoComplete
#define CLI_LR_KEY_EN                       (1)            // Move cursor left-rigth
#define CLI_DEFAULT_ALLOC_EN                (0)            // Default Memory Allocate functions (use static or malloc memmory for add new command)
#define CLI_DEFAULT_STRING_EN               (1)            // Default String functions
#define CLI_PRINT_ERROR_EXEC_EN             (1)            // Print error after execute command
#define CLI_PRINT_ERROR_ADD_CMD_EN          (1)            // Print error after added command
#define ECHO_EN                             (1)            // Enter echo enable

// **************************************************************************

// *************************   IO CLI Settings    ***************************
void CLI_PrintStr(char* str);
void CLI_PrintChar(char c);

extern char dbgbuffer[128];
#define CLI_Printf(...)         {sprintf(dbgbuffer,__VA_ARGS__);CLI_PrintStr(dbgbuffer);}
#if (ECHO_EN == 1)
#define CLI_PutChar             CLI_PrintChar
#else	// ECHO_EN != 1 ECHO off
#define CLI_PutChar
#endif  // ECHO_EN == 1

// **************************************************************************
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

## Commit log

2020-05-04 refacor lib ssd1306, fix time, add get battery info ico
    [OLED_UI.c, main_app.c]
2020-05-15 add RTC BKP register, implement func FIND new Battery
2020-05-23 add charger chip BQ25895
2020-05-23 fix save new Settings for BQ27441 and find new battery
    [BQ27441.c, OLED_UI.c, Power.c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]
2020-05-30 add schematic
    [mid.STL, top.STL]
2020-05-30 Update README.md
    add STL
2020-06-04 add debug interface: use printf on USB, add version FW, debug bq27441
2020-06-04 use printf on USB, add version FW, debug bq27441
2020-06-04 add support bootloader, CLI flasher, change VECT_TAB_OFFSET 0x00000800U
    use printf on USB, add version FW, debug bq27441
2020-06-08 set min volt
2020-06-08 remove reset, set min and terminate voltage
    [Power.c, main_app.c]
2020-06-21 * fix power off * add new current icon
    [OLED_UI.c, main_app.c]
2020-06-21 fix timmer power off
    [Power.c]
2020-06-21 debug timmer auto power off
2020-08-20 fixed auto-power off
2020-08-21 added read information from TrueRamaining Capacity register in bq27441
2020-08-21 time measurements during charging
2020-08-21 fix auto power off
    [Power.c]
2020-08-27 added configuration files for OpenOCD debuger
    [stmf1xx-jlink.cfg, stmf1xx-stlink.cfg]
2020-08-31 refactor & fix up calculate mah, init app
    [BQ27441.c, OLED_UI.c, Power.c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]
2020-08-31 Develop (#20)
    * Refactor (#19)
    * refactor code
    * Refactor code
    * refactor
    * refactor
    * fixed auto-power off
    * added read information from TrueRamaining Capacity register in bq27441
    * time measurements during charging
    * fix auto power off
    * Update CMake
    * added tinyprinf for embedded applications
    * refactor&optimisation code
    * need debug tinyprintf
    * added copy eeprom data in FullFW.bin adress 1FC00, physical adress in STM 0x801FC00
    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
    [BQ27441.c, FatShark_Power_V1.ioc, OLED_UI.c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]
2020-08-31 set terminate voltage 2950mV
2020-08-31 fix: BQ27441 set current settings for Liion battery
    [Power.c]
2020-09-17 disable button interrupt, when pushed (for bounce button), need refactor button event and add callback, refactor power.c
2020-09-17 refactor button events, one push one handled event
    refactor UI, new button events
    clean up variable
    update README.md
    new implement button
    increment version
2020-11-07 Develop (#23)
    * disable button interrupt, when pushed (for bounce button), need refactor button event and add callback, refactor power.c
    * refactor button events, one push one handled event
    * added CLI, removed tomep autooff, added buzzer, minor fix, refactor code,
    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
    [OLED_UI.c, Power.c]
2020-11-07 Develop (#24)
    * added travis CI
    * travis CI, test build
    setup Travis CI
    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
2020-11-15 add print Unique ID MCU via LI
2020-11-15 refactor main.c (#29)
    * add print Unique ID MCU via LI
    * refactor cli module
    * refactor main.c
2020-11-21 Refactor CMake & refactor folders (#30)
    * Refactor CMake, refactor folder
    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
